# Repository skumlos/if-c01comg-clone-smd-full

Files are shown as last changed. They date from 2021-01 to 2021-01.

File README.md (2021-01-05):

IF-C01COMG Clone board SMD Full size

This is a full sized version of the IF-C01COMG board for JVC pro monitors (TM-Hxx50CG) and some others...

It's basically the THT base board I made some months ago, with most components changed to SMD.

Credit goes to James Vanderloeff for the dual input idea.

Board is for now completely untested...

Finally this is a Kicad 5.1 project :D

You're welcome to clone, sell, re-design and whatever, see LICENSE.

(2021) Martin Hejnfelt (martin@hejnfelt.com)
This work is free. You can redistribute it and/or modify it under the
terms of the Do What The Fuck You Want To Public License, Version 2,
as published by Sam Hocevar. See the LICENSE file for more details.

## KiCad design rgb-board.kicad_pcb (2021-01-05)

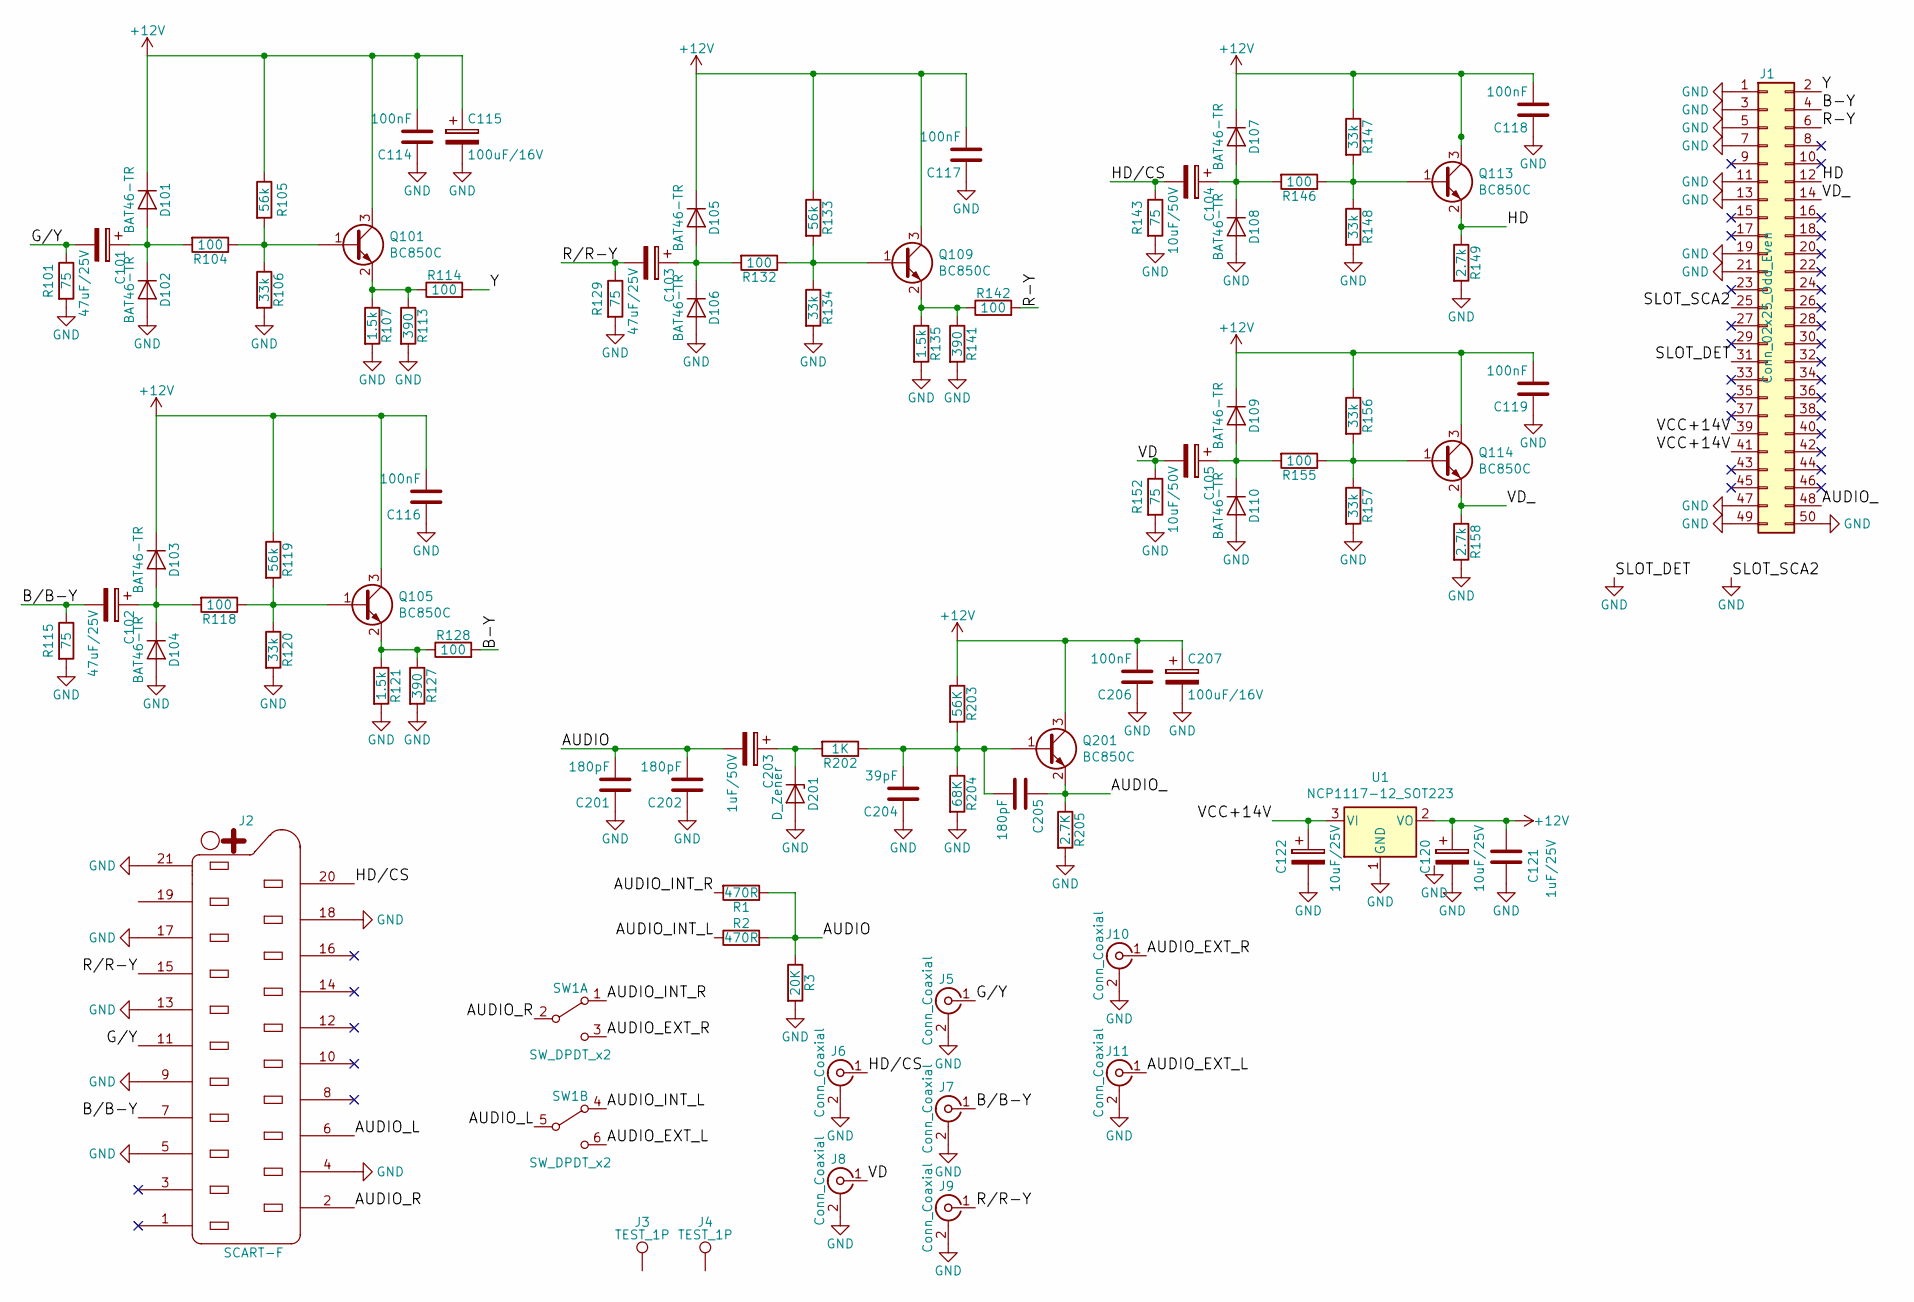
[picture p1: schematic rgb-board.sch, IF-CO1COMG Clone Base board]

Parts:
C101, C102, C103: 47uF/25V; C_Elec_6.3x5.4
C104, C105: 10uF/50V; C_Elec_5x5.4
C114, C116, C117, C118, C119, C206: 100nF; C_0805_2012Metric_Pad1.18x1.45mm_HandSolder
C115, C207: 100uF/16V; C_Elec_6.3x5.4
C120, C122: 10uF/25V; C_Elec_5x5.4
C121: 1uF/25V; C_0805_2012Metric_Pad1.18x1.45mm_HandSolder
C201, C202, C205: 180pF; C_0805_2012Metric_Pad1.18x1.45mm_HandSolder
C203: 1uF/50V; C_Elec_4x5.4
C204: 39pF; C_0805_2012Metric_Pad1.18x1.45mm_HandSolder
D101, D102, D103, D104, D105, D106, D107, D108, D109, D110: BAT46-TR; D_SOD-123
D201: D_Zener; D_SOD-123
J1: Conn_02x25_Odd_Even; Pin_Header_Angled_2x25_Pitch2.54mm
J2: SCART-F; NINIGI-SCART-RA
J3, J4: TEST_1P; MountingHole_3.2mm_M3
J5, J6, J7, J8, J9: Conn_Coaxial; BNC-THT
J10, J11: Conn_Coaxial; RCJ-04X
Q101, Q105, Q109, Q113, Q114, Q201: BC850C; SOT-23_Handsoldering
R1, R2: 470R; R_0805_2012Metric_Pad1.20x1.40mm_HandSolder
R3: 20K; R_0805_2012Metric_Pad1.20x1.40mm_HandSolder
R101, R115, R129, R143, R152: 75; R_0805_2012Metric_Pad1.20x1.40mm_HandSolder
R104, R114, R118, R128, R132, R142, R146, R155: 100; R_0805_2012Metric_Pad1.20x1.40mm_HandSolder
R105, R119, R133: 56k; R_0805_2012Metric_Pad1.20x1.40mm_HandSolder
R106, R120, R134, R147, R148, R156, R157: 33k; R_0805_2012Metric_Pad1.20x1.40mm_HandSolder
R107, R121, R135: 1.5k; R_0805_2012Metric_Pad1.20x1.40mm_HandSolder
R113, R127, R141: 390; R_0805_2012Metric_Pad1.20x1.40mm_HandSolder
R149, R158: 2.7k; R_0805_2012Metric_Pad1.20x1.40mm_HandSolder
R202: 1K; R_0805_2012Metric_Pad1.20x1.40mm_HandSolder
R203: 56K; R_0805_2012Metric_Pad1.20x1.40mm_HandSolder
R204: 68K; R_0805_2012Metric_Pad1.20x1.40mm_HandSolder
R205: 2.7K; R_0805_2012Metric_Pad1.20x1.40mm_HandSolder
SW1: SW_DPDT_x2; LC2259
U1: NCP1117-12_SOT223; SOT-223-3_TabPin2

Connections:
+12V: C114.2, C115.1, C116.2, C117.2, C118.2, C119.2, C120.1, C121.2, C206.2, C207.1, D101.1 (K), D103.1 (K), D105.1 (K), D107.1 (K), D109.1 (K), Q101.3 (C), Q105.3 (C), Q109.3 (C), Q113.3 (C), Q114.3 (C), Q201.3 (C), R105.1, R119.1, R133.1, R147.1, R156.1, R203.1, U1.2 (VO)
/AUDIO: C201.2, C202.2, C203.2, R1.1, R2.2, R3.1
/AUDIO_: C205.1, J1.48, Q201.2 (E), R205.1
/AUDIO_EXT_L: J11.1 (In), SW1.6 (C)
/AUDIO_EXT_R: J10.1 (In), SW1.3 (C)
/AUDIO_INT_L: R2.1, SW1.4 (A)
/AUDIO_INT_R: R1.2, SW1.1 (A)
/AUDIO_L: J2.6, SW1.5 (B)
/AUDIO_R: J2.2, SW1.2 (B)
/B-Y: J1.4, R128.2
/B/B-Y: C102.2, J2.7, J7.1 (In), R115.1
/G/Y: C101.2, J2.11, J5.1 (In), R101.1
/HD: J1.12, Q113.2 (E), R149.1
/HD/CS: C104.2, J2.20, J6.1 (In), R143.1
/R-Y: J1.6, R142.2
/R/R-Y: C103.2, J2.15, J9.1 (In), R129.1
/VCC+14V: C122.1, J1.39, J1.41, U1.3 (VI)
/VD: C105.2, J8.1 (In), R152.1
/VD_: J1.14, Q114.2 (E), R158.1
/Y: J1.2, R114.2
GND: C114.1, C115.2, C116.1, C117.1, C118.1, C119.1, C120.2, C121.1, C122.2, C201.1, C202.1, C204.1, C206.1, C207.2, D102.2 (A), D104.2 (A), D106.2 (A), D108.2 (A), D110.2 (A), D201.2 (A), J1.1, J1.3, J1.5, J1.7, J1.11, J1.13, J1.19, J1.21, J1.25, J1.31, J1.47, J1.49, J1.50, J2.4, J2.5, J2.9, J2.13, J2.17, J2.18, J2.21, J5.2 (Ext), J6.2 (Ext), J7.2 (Ext), J8.2 (Ext), J9.2 (Ext), J10.2 (Ext), J11.2 (Ext), R3.2, R101.2, R106.2, R107.2, R113.2, R115.2, R120.2, R121.2, R127.2, R129.2, R134.2, R135.2, R141.2, R143.2, R148.2, R149.2, R152.2, R157.2, R158.2, R204.2, R205.2, U1.1 (GND)
unnamed: C101.1, D101.2 (A), D102.1 (K), R104.2
unnamed: C102.1, D103.2 (A), D104.1 (K), R118.2
unnamed: C103.1, D105.2 (A), D106.1 (K), R132.2
unnamed: C104.1, D107.2 (A), D108.1 (K), R146.2
unnamed: C105.1, D109.2 (A), D110.1 (K), R155.2
unnamed: C203.1, D201.1 (K), R202.2
unnamed: C204.2, C205.2, Q201.1 (B), R202.1, R203.2, R204.1
unnamed: Q101.1 (B), R104.1, R105.2, R106.1
unnamed: Q101.2 (E), R107.1, R113.1, R114.1
unnamed: Q105.1 (B), R118.1, R119.2, R120.1
unnamed: Q105.2 (E), R121.1, R127.1, R128.1
unnamed: Q109.1 (B), R132.1, R133.2, R134.1
unnamed: Q109.2 (E), R135.1, R141.1, R142.1
unnamed: Q113.1 (B), R146.1, R147.2, R148.1
unnamed: Q114.1 (B), R155.1, R156.2, R157.1

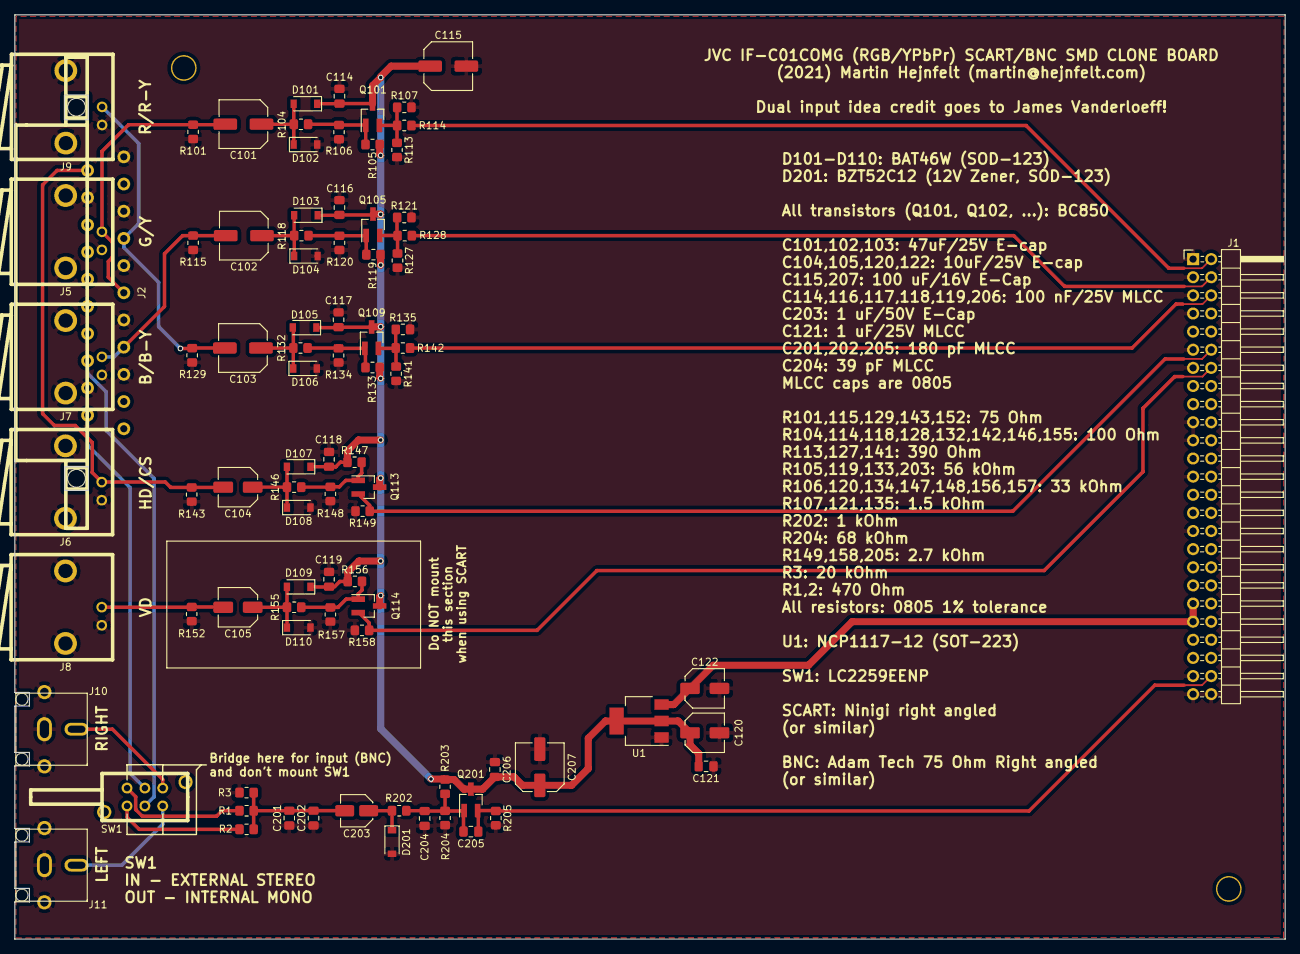
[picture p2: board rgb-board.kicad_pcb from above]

Board: 2 copper layers, 178.0 x 129.5 mm, 89 parts (0 on the bottom side), 36 nets.
